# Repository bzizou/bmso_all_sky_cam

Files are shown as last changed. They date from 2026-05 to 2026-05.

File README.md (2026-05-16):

# BMSO All-sky DIY camera

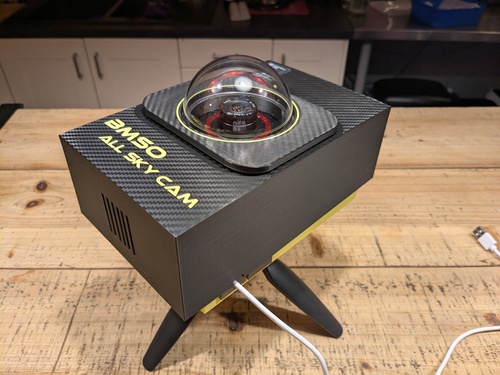
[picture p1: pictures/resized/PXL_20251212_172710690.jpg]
Picture of BMSO all-sky cam
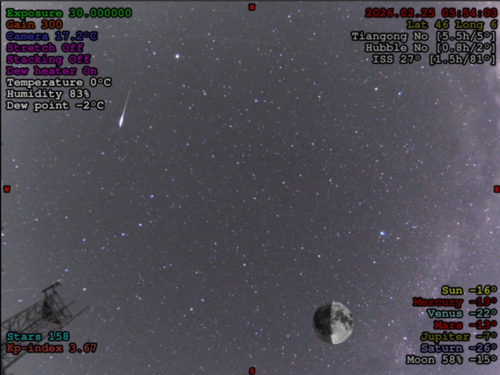
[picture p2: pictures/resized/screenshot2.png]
  

## Introduction
BMSO is the name of my personnal mobile observatory. I wanted a small portable "all-sky" camera to put on the roof of my van during the nights I spend astrophotographing the dark skies. The goal is to monitor the sky and environmental data (humidity/temperature/dew point, clouds, comming rain,...) and by the way make some nice timelapses of the rotating sky. Such a camera is generally expensive and not very easy to use as a mobile device. So, here's my own DIY all-sky camera. I's build around a [ZWO ASI 224MC](https://www.zwoastro.com/product/zwo-asi224mc/), but you can use any other [Indi](https://indilib.org/) supported device. The advantage of this 224MC model is that it already comes with a small wide angle objective that you can directly use in this setup, and it's relatively inexpensive. I found mine as a second hand for 150 €.

The case of the camera is made with a 3D printer in PETG and the "brain" is a [Raspberry-Pi 5](https://www.raspberrypi.com/products/raspberry-pi-5/) with 2 GB of RAM, but it should work with a less expensive model RP-4.

The software stack is fully opensource: [Raspbery Pi OS](https://www.raspberrypi.com/software/operating-systems/) (Linux Debian based) with [Indi](https://indilib.org/) and the excellent [Indi allsky](https://github.com/aaronwmorris/indi-allsky) project.

The whole thing may cost you less than 200 €

The power supply is a simple USB cable. I use a 27000 mAh USB power tank and it easily runs a full 12 hours night by 0°C.

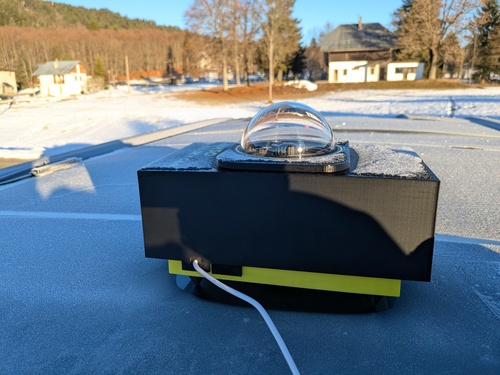
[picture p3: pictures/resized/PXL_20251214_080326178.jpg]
Picture of BMSO all-sky cam
 

You can check some sample timelapses [here](sample_timelapses/)

## Needed skills

This Readme assumes you're a bit familiar with DIY projects involving 3d printing, Paspberry-Pi OS (Linux) usage, GPIO pins usage and minimal electronic circuits and components knowledge. This small doc is not very exhaustive, but you're encouraged to check the files into the subdirectories of the project. The pictures should help and dont't hesitate to create an issue if you need some informations.

## List of supplies

- [ZWO ASI 224MC](https://www.zwoastro.com/product/zwo-asi224mc/) camera or any [Indi](https://drivers.indilib.org/cameras/) compatible device. As any astronomy camera, the more sensible the best. Avoid too small sensors as it will reduce the field of view.
- A wide angle CS-mount Lens, if your camera does not already have one. This one should be better than the one in the box of the 224MC which is only 150 degrees : [ZWO CCTV Lens 2.5 mm 170 Degrees - for ASI cameras without cooling](https://www.teleskop-express.de/en/astrophotography-and-photography-15/other-photo-accessories-143/zwo-cctv-lens-2-5-mm-170-degrees-for-asi-cameras-without-cooling-1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)
- A [Raspberry-Pi](https://www.raspberrypi.com/). A Pi 5 is great but a v4 should also work. The more RAM the best. Mine is a PI 5 with 2 GB and it works perfectly. Boght [here](https://www.elektor.fr/products/raspberry-pi-5-2-gb-ram) for 50 €.
- A case for Raspberry-Pi. This is not mandatory, but best to prevent from a bad cooling. I used a passive cooling aluminium case as the BMSO all-sky cam provides cooling with a fan that is also used for best efficiency of the humidity sensor. The exact model I used is the Geekworm [Raspberry Pi 5 Heavy-duty Aluminum Passive Cooling Case (P573)](https://www.amazon.fr/Geekworm-Raspberry-bo%C3%AEtier-Aluminium-Passive/dp/B0CNPL3V55). 
- A transparent plastic dome generally used for CCTV cameras. I used [this one](https://a.aliexpress.com/_EvziIdy), but if you have a slighter different one, you may choose to modify the "adapter" piece of the body in the 3D parts. To use the provided adapter, you have to choose a dome that has an exact **84.5** mm external diameter at the base.
- Optional but highly recommended: the list of electronics components to build the **dew heater**:
  - x8 100 Ohms resitors 1/4W
  - x1 2k Ohms resistor
  - x1 220 Ohms resistor
  - x1 BD 139 NPN transistor
  - x1 red LED
  - A piece of veroboard
  - A small piece of raw aluminium plate easy to cut and drill (2mm thick max) to build a radiator for the transistor
  - Some colored dupont jumpers (to connect to the Raspberry Pi)
- Optional, the Fan and the electronic coponents for the current PWM adaptator:
  - x1 Fan 5V 40 mm (for example a USB kit [like this](https://www.amazon.fr/dp/B0D416SDZN), but the switch is useless for us)
  - x1 1k Ohms resistor
  - x1 10 uF capacitor (just to smooth the signal and reduce the noise of the fan)
  - x1 diode
  - x1 NPN transistor (any 2N2222, BC237 or so)
  - A piece of veroboard
  - A small piece of raw aluminium plate easy to cut and drill (2mm thick max) to build a radiator for the transistor
- Optional, the temperature and humidity sensor:
  - x1 RHT03 or DHT22 humidity sensor
  - Some colored dupont jumpers (to connect to the Raspberry Pi)
- Of course, you'll need some plastic filaments and a 3D printer (or a friend having one!):
  - 2 colors of generic PETG (you can use only one color, but this will be less stylish!)
  - Some translucent PETG, for the leds of the R-Pi to be visible
  - A bit of black TPU, for the cable pass-through
- Some velcro stickers to fix the parts of the case together
- A kodak female 1/4" insert

## The case

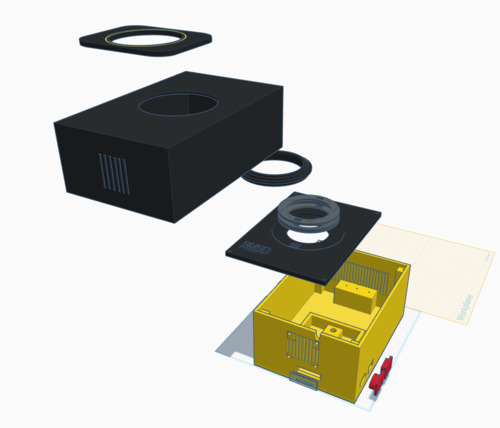
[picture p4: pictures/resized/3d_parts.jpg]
3D case


If you have a Bambulab printer, the [project file](BMSO All Sky Cam.3mf) is for you. Else, you have all the parts file in the STL format [here](3D_parts)

Print all the parts, and glu the adapter into the whole of the water proof cover with silicon.

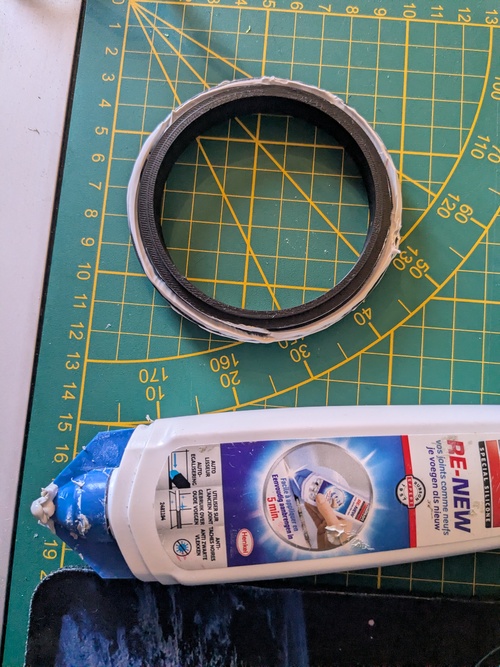
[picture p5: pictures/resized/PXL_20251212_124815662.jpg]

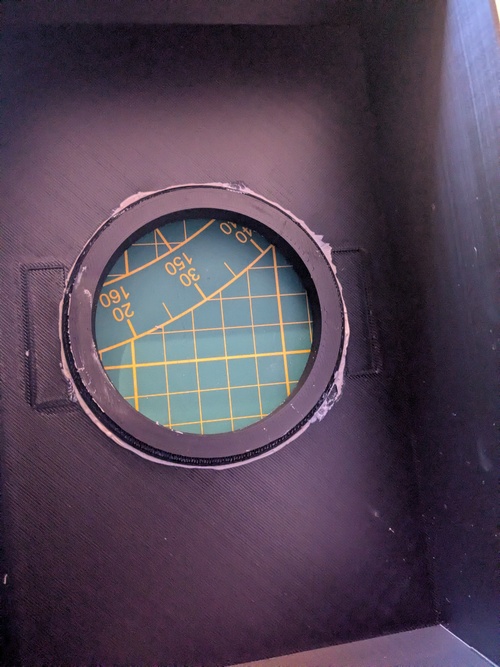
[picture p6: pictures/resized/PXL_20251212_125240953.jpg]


Hot the insert with a lighter and insert it into the back hole:

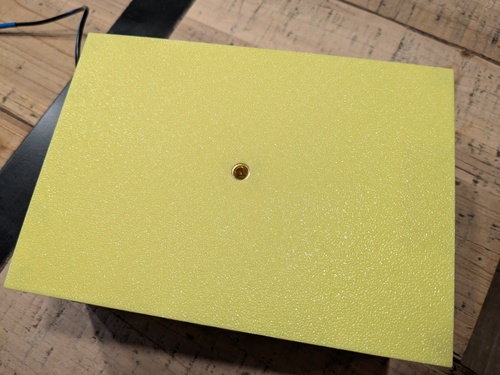
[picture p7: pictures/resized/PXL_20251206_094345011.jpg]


## Camera and Raspberry-pi installation

TBC...

## The Fan

Fix the fan on the outside grid near the raspberry with some little screws, or glue it.

Here's the circuit to connect the FAN to a PWM pin of the raspberry. Indi-allsky has all the necessary options to set it up later.

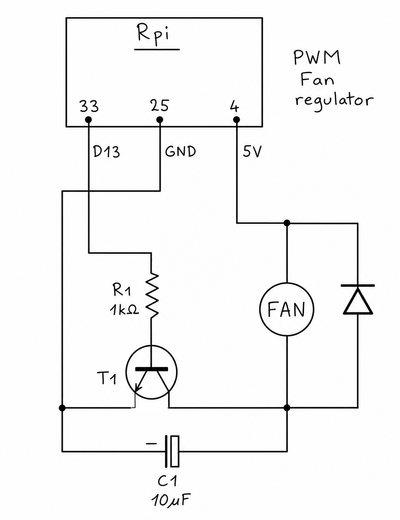
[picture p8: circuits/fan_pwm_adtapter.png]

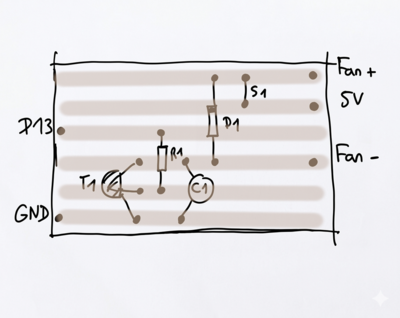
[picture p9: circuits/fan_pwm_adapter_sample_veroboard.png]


## The Dew heater

The dew heater is composed of 8 resitors and a power circuit to deliver up to 2W throught the resistors. The regulation is made with a PWM pin of the respberry pi. The indi-all sky software has options to control this regulator in function of the calculated dew point with values from the humidity and temperature sensor. For better accuracy of the dew point calculation, I recommend the installation of the fan, as it helps the humidity sensor to measure the humidity of the outside air (and not the air from the inside of the case, which is not at the same temperature/humidity because of the heating provided by the Raspberry-Pi)

You have to weld the resistors in parallel using stripped wires and passing them throught the support:

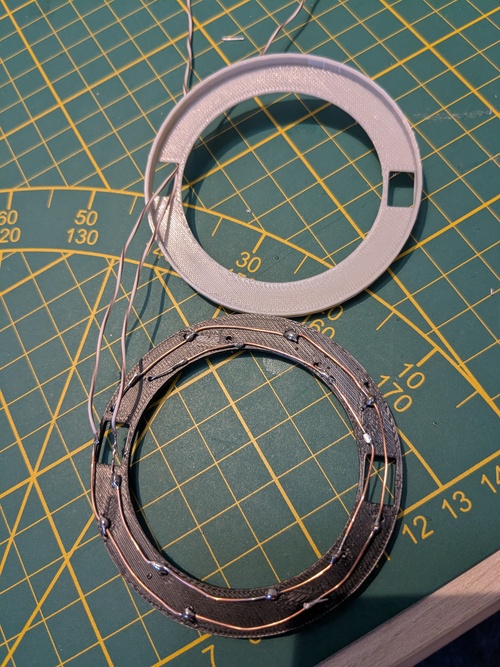
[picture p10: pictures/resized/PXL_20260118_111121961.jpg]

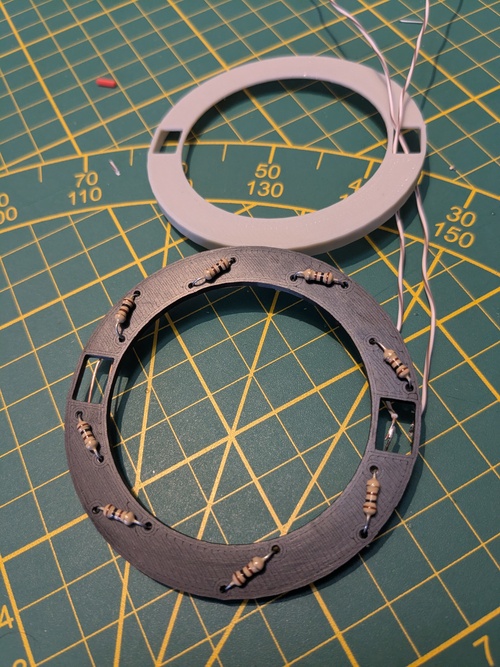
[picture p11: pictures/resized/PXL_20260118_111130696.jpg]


Then, glue the 2 parts of the heater together:

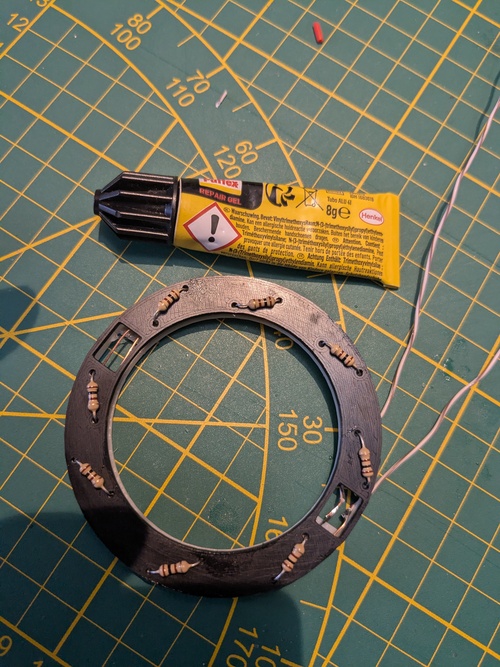
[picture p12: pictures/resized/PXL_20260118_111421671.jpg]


Build the regulation circuit:

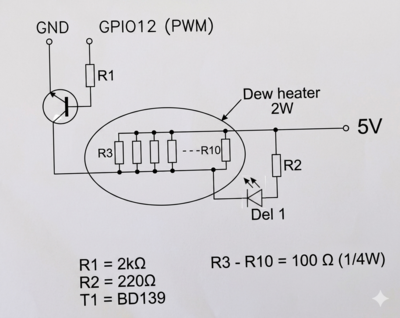
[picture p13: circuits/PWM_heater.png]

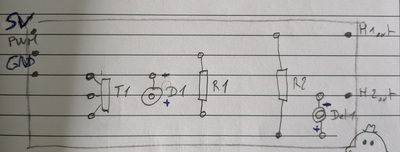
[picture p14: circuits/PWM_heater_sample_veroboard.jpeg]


And connect it to the raspberry. Don't forget to add a dissipator to the BD139 transistor, or it will heat too much. Fix the circuit near the inlet grid so that you can see the RED led lighting when the heater is on.

## The humidity sensor

TBC...

## All together, in the inside

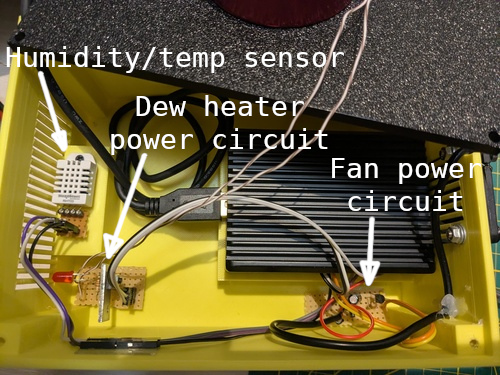
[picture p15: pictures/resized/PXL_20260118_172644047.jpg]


## The software stack

TBC...

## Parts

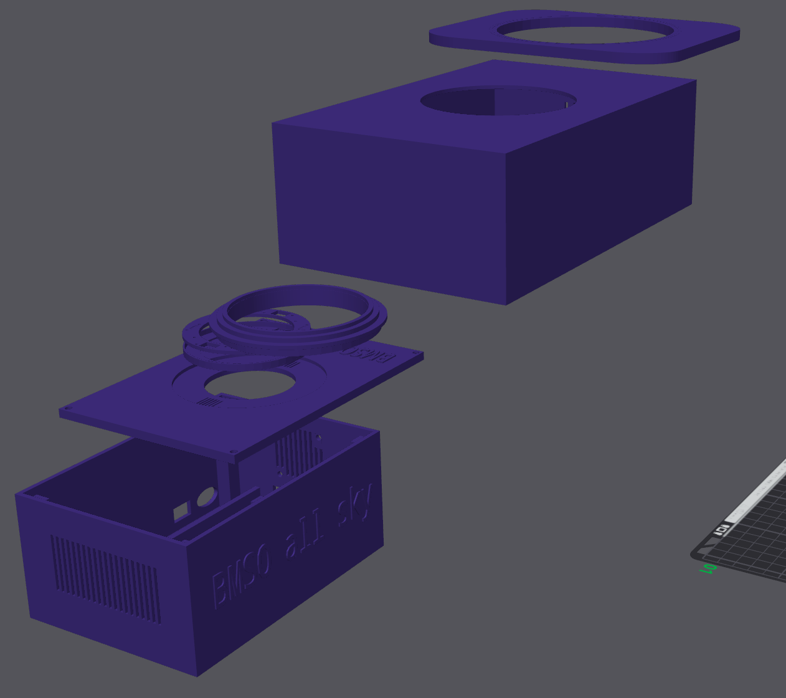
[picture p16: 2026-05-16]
3D_parts/screenshot2.png

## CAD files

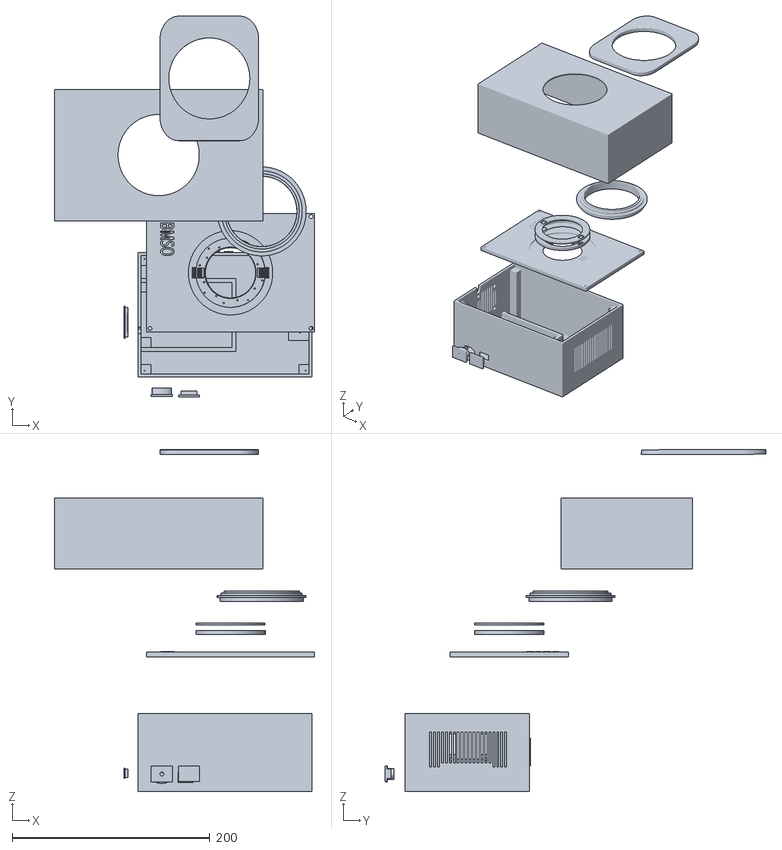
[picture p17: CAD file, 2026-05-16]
3D_parts/BMSO allsky v3.1_all_parts.stl
263.2 x 385.2 x 346.0

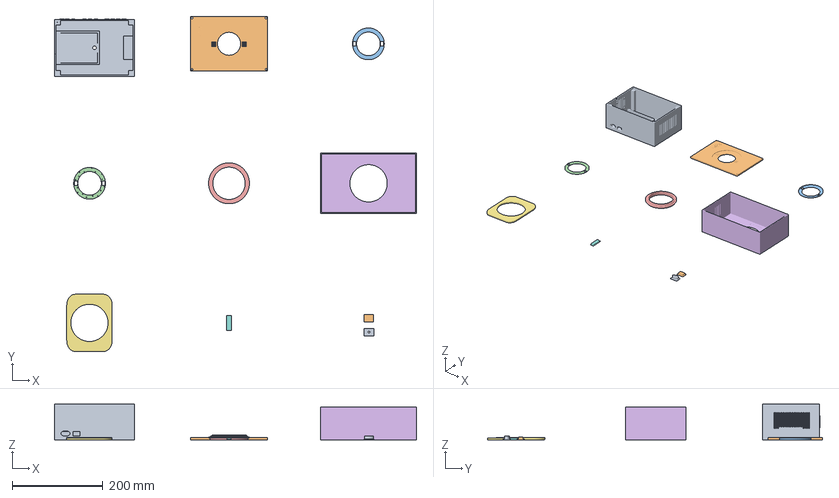
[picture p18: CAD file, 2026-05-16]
BMSO All Sky Cam.3mf
796.9 x 737.4 x 79.0 mm
Body.stl
Top.stl
Heater_bottom.stl
Heater_top.stl
Adapter.stl
Water_proof_cover.stl
Dome_fix.stl
Pi_leds_window.stl
Cable_pass_through_1.stl
Cable_pass_through_2.stl

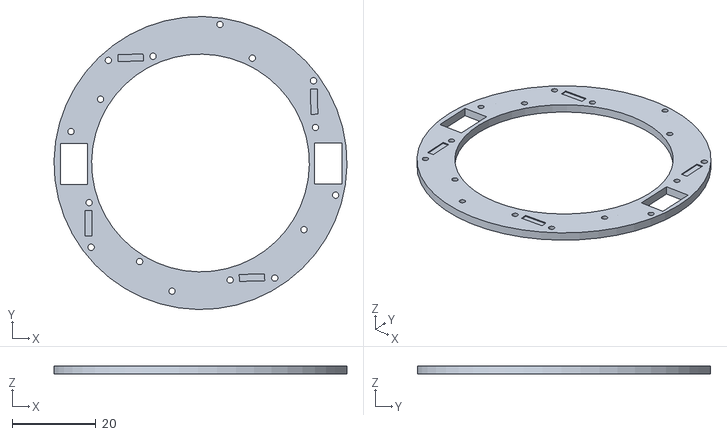
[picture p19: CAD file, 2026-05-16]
3D_parts/Heater_top.stl
70.0 x 70.0 x 2.00

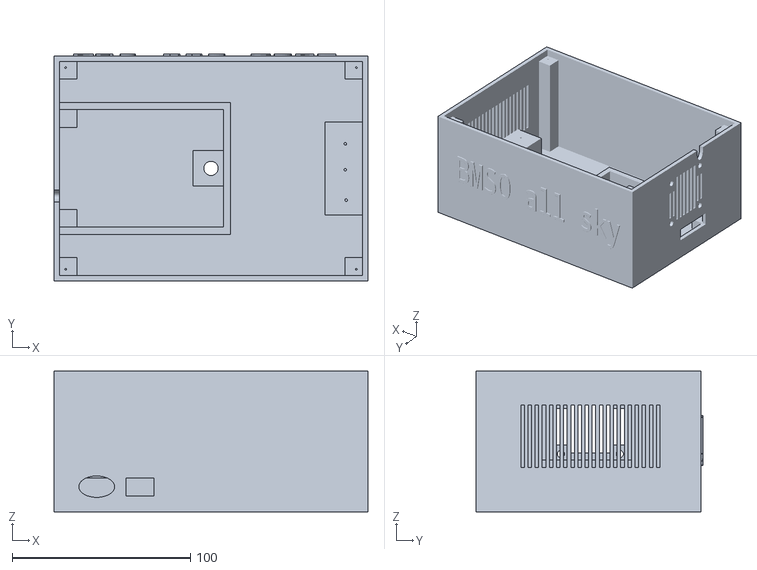
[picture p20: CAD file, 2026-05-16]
3D_parts/Body.stl
176.0 x 127.0 x 79.0

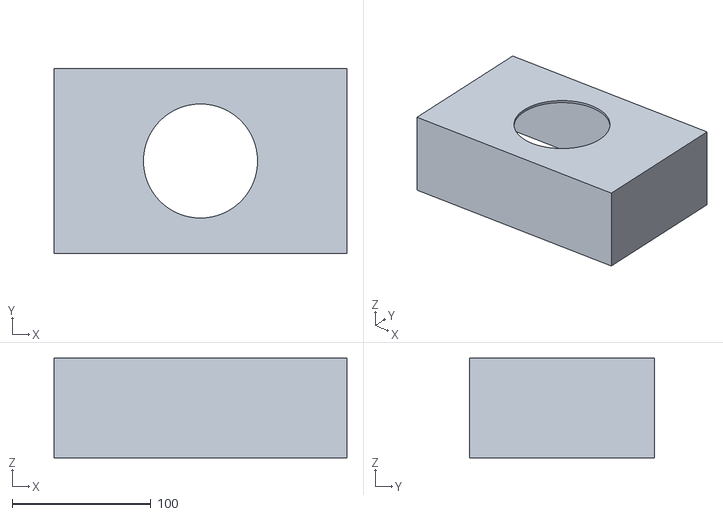
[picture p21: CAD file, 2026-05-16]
3D_parts/Water_proof_cover.stl
211.0 x 133.0 x 72.0

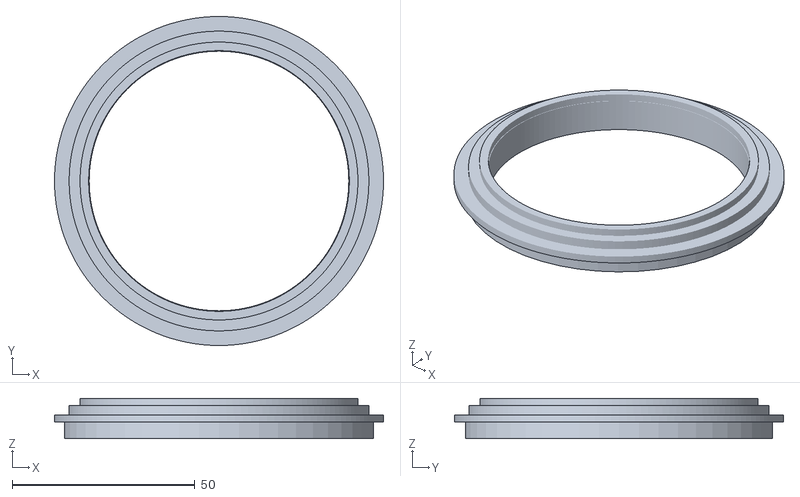
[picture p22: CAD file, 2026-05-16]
3D_parts/Adapter.stl
90.0 x 90.0 x 11.0

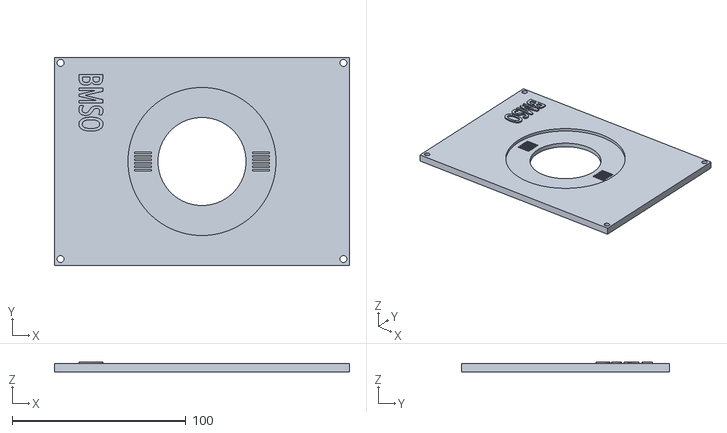
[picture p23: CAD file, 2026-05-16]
3D_parts/Top.stl
170.0 x 120.0 x 5.90

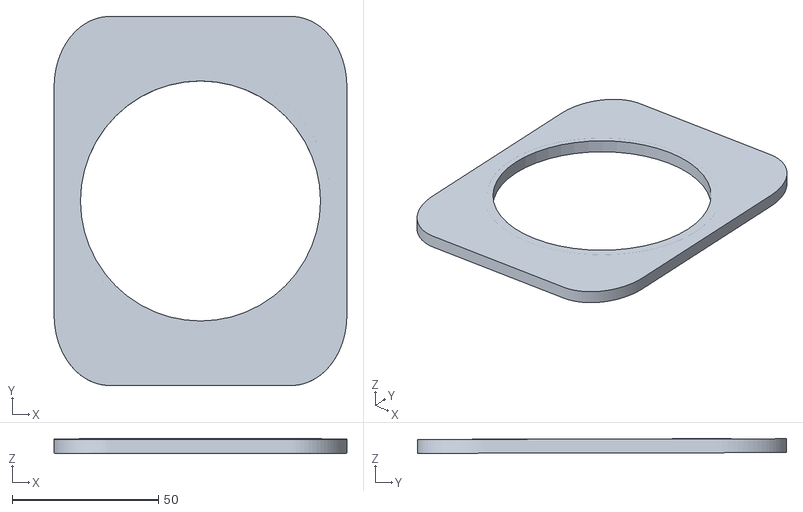
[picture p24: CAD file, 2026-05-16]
3D_parts/Dome_fix.stl
100.0 x 126.1 x 5.04

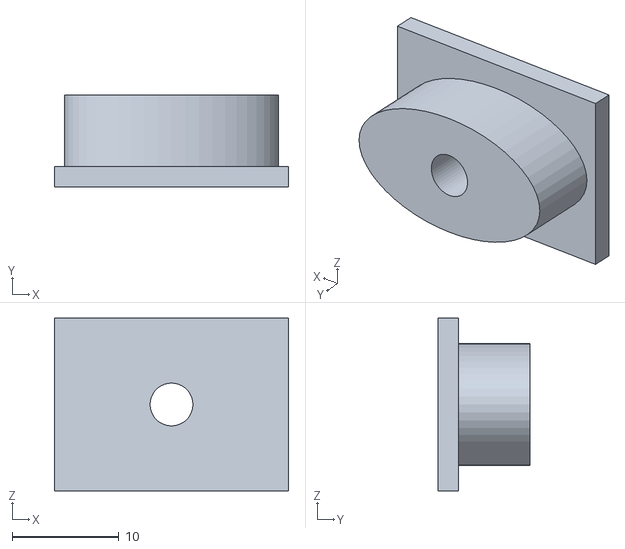
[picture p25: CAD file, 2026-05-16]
3D_parts/Cable_pass_through_1.stl
21.9 x 8.57 x 16.2

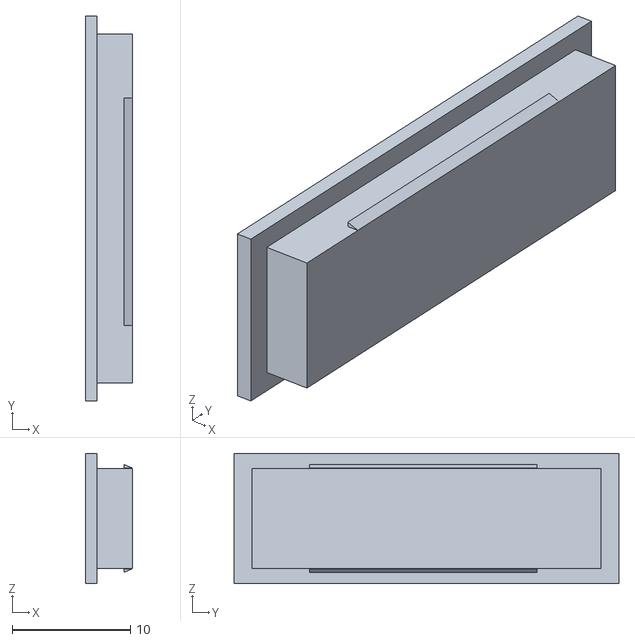
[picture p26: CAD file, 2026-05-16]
3D_parts/Pi_leds_window.stl
4.00 x 32.6 x 11.0

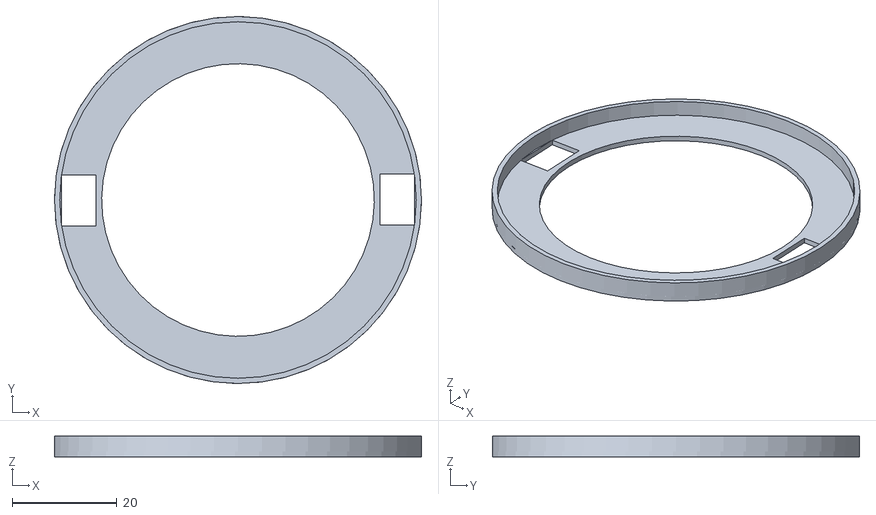
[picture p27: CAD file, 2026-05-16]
3D_parts/Heater_bottom.stl
70.0 x 70.0 x 4.00

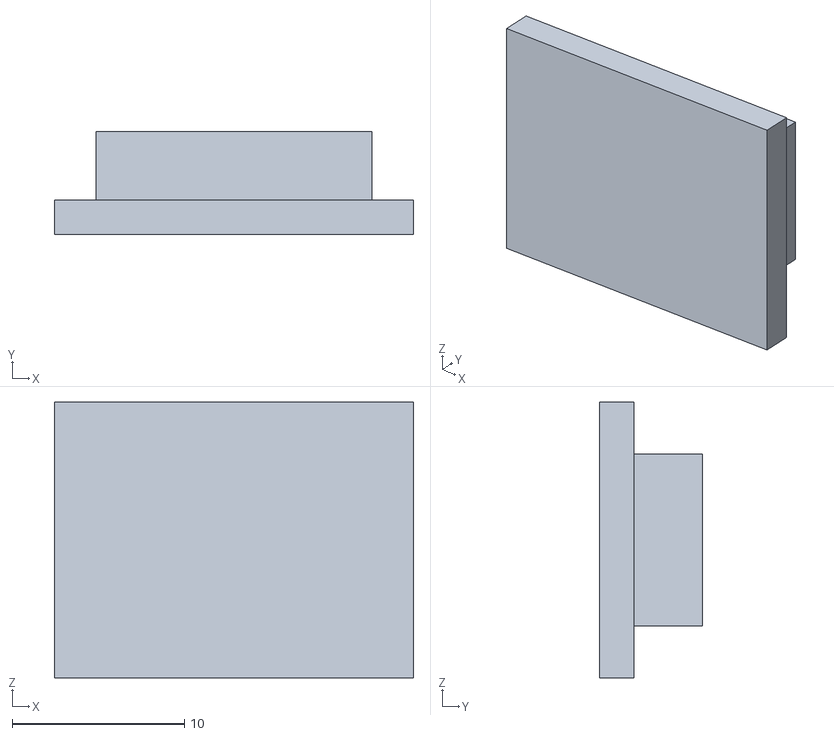
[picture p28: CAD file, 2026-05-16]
3D_parts/Cable_pass_through_2.stl
20.8 x 6.00 x 16.0

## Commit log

2026-05-16 Expand README with project introduction and details
    Added introduction section detailing the BMSO all-sky camera project, including its purpose, components, and software stack.
2026-05-16 Add images to README for BMSO all-sky camera
    Added images to the README for better visualization.
2026-05-16 Update README with corrected specifications and typos
    Corrected RAM specification for Raspberry Pi and fixed typos in links and image paths.
2026-05-16 Enhance README with assembly instructions and images
    Updated the README with additional materials and images for the 3D case assembly.
2026-05-16 Revise assembly instructions and add installation section
    Updated instructions for assembly and added section for camera and Raspberry Pi installation.
2026-05-16 Resized curcuits pictures and updated 3mf project
    [BMSO All Sky Cam.3mf]
2026-05-16 Enhance fan section with repair instructions and diagrams
    Updated instructions for fixing the fan and added circuit images.
2026-05-16 Document dew heater assembly and operation
    Added detailed description of the dew heater, including components, assembly instructions, and circuit connections.
